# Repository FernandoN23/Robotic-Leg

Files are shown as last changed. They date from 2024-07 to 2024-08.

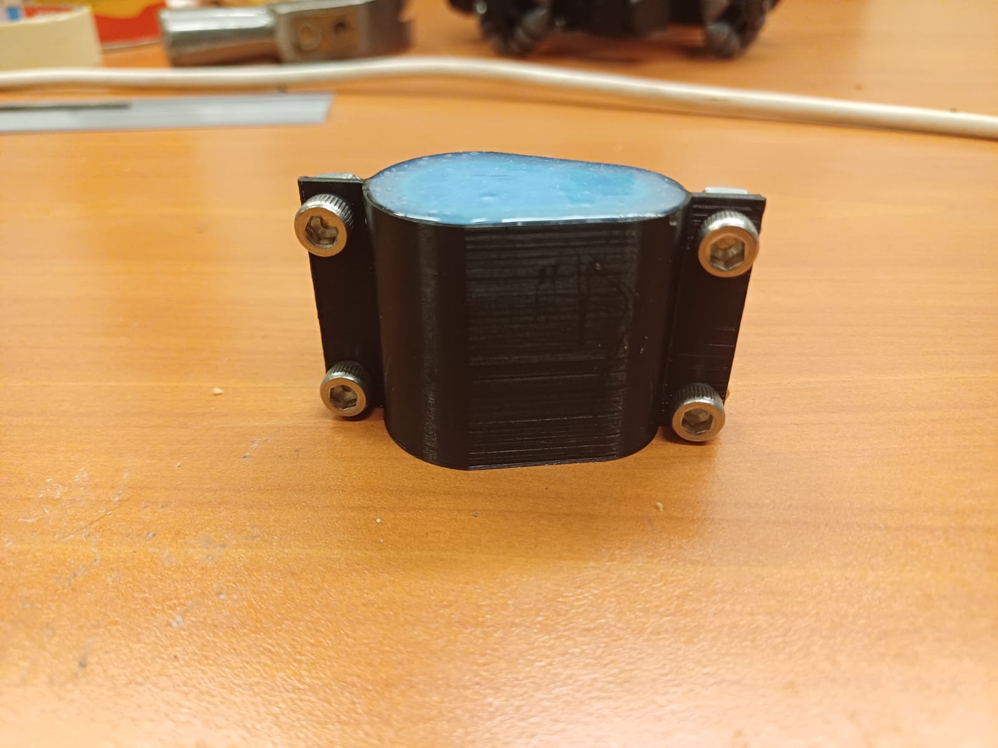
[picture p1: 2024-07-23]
Soft Robotic/Registro fotográfico/Pie mojado/Pie mojado en molde (foto 3).jpeg

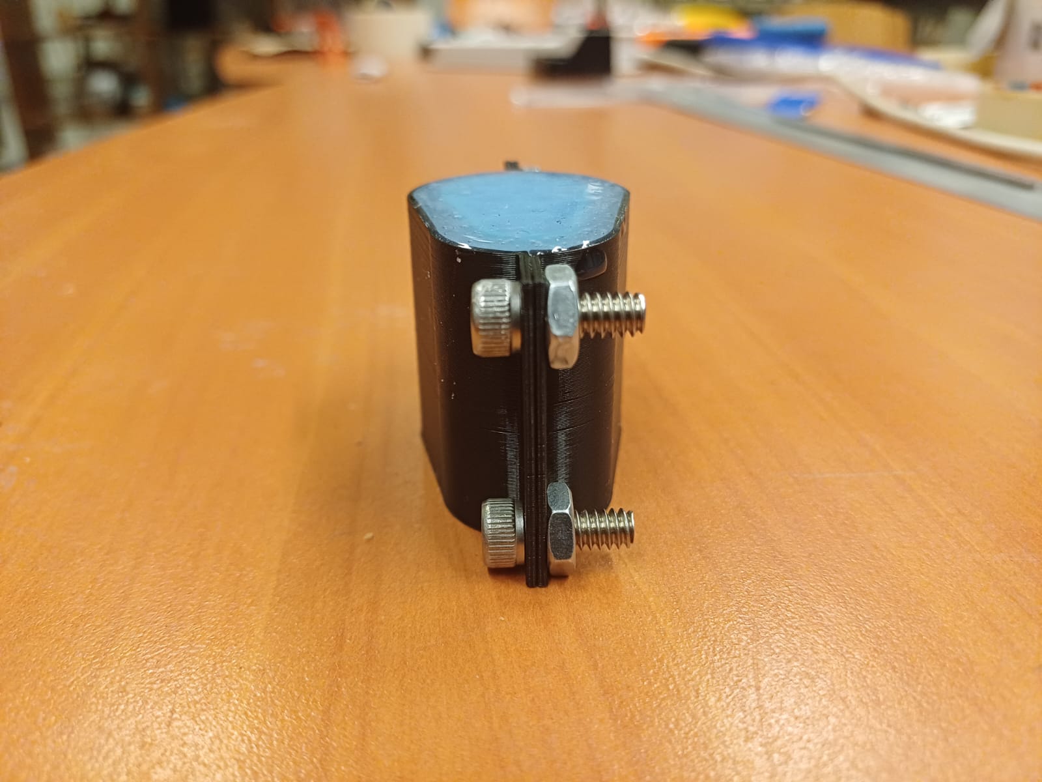
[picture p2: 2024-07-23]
Soft Robotic/Registro fotográfico/Pie mojado/Pie mojado en molde (foto 1).jpeg

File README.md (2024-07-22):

# Robotic-Leg
Proyecto de Trabajo Dirigido Avanzado ME5102 el cual consiste en la elaboración de una pata robótica utilizando robótica rígida y blanda. Elaborado en la Facultad de Ciencias Físicas y Matemáticas de la Universidad de Chile.

Objetivo general: Diseñar y manufacturar una pata robótica. 

Objetivos específicos:
- La pata robótica será un diseño híbrido, creada a partir de robótica rígida y blanda.
- La pata robótica será funcional y tendrá un enfoque educativo y didáctico.
- La pata robótica será de fácil ensamblaje para futuros proyectos y/o modificaciones.
- Esta pata será el elemento principal para un robot bípedo o cuadrúpedo.

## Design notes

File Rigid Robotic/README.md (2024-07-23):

# Robótica Rígida

En esta carpeta se encuentran todos los archivos CAD, scripts y diseños relacionados a la robótica rígida de la pata robótica.

El diseño de la pata robótica considera 4 eslabones, donde dos de ellos (pata superior e inferior) corresponden a las piezas principales y las otras se tratan de piezas que permiten la transmisión del movimiento en todo el sub-sistema dando lugar a su locomoción a través de pisadas.

Para la estructura del sub-sistema también se utilizaron los siguientes componentes comerciales:
- Rodamientos:
  - 6804 (20x32x7 mm)
  - 685 (5x11x5 mm)
- Tornillos sinfín:
  - Tornillo de largo 6,5 cm
  - Tornillo de largo 20 cm
 
Luego, para la implementación del movimiento se utilizaron los componentes comerciales electrónicos de a continuación:
- Motor Stepper NEMA 17

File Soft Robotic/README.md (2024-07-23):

# Soft Robotic

En esta carpeta se encuentran todos los archivos CADs y diseños relacionados a la robótica blanda de la pata robótica.

Se aplicaron bases de robótica blanda para diseñar el "pie" de la pata robótica. Una de las consideraciones principales de diseño para el pie de la pata fue otorgarle una característica de tipo modular, que permita no sólo cambiarlo en términos de diseño, sino que agregarle un valor agregado al desarrollo de este trabajo, puesto que esta particularidad también ofrece la oportunidad de experimentar con diferentes piezas, materialidades y geometrías.

Se llevaron a cabo dos tipos de "pie" a partir de robótica blanda: "Pie mojado" y "Pie runner".

Para el pie mojado se realizó una simulación estática. Se consideró una fuerza vertical de 700 N, donde se obtuvo un esfuerzo máximo de Von Mises de 13,825 MPa y un factor de seguridad de 3,139, considerando como material: PLA. Se tiene en cuenta un factor de seguridad mínimo aceptable de 3,0 debido a que dicho material es de tipo anisotrópico en impresión 3D.

Para la realización de las piezas se precisaron principalmente siliconas Dragon Skin™ (10 Medium), las cuales corresponden compuestos de silicona líquida curados con platino de alto rendimiento.

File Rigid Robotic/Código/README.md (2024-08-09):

Aquí se presenta el código de prueba para este sistema mecánico.

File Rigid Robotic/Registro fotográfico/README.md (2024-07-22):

# Registro fotográfico

En esta sección se almacenará todo el registro fotográfico generado a lo largo de ejecución del trabajo realizado.

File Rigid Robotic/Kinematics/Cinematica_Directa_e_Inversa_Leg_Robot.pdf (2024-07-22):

Universidad de Chile
Facultad de Ciencias Físicas y Matemáticas Departamento de Ingeniería Mecánica ME5102-2 – Trabajo dirigido avanzado

# Proyecto Pata robótica

Trabajo Dirigido Avanzado

Profesores: Rubén Fernández, Carolina Silva Estudiantes: Juan Manuel Astudillo, Francisco Cáceres, Lucas Garrido, Fernando Navarrete, Nicole Ortiz, Randy Bartolo,

## 1. Cinemática Directa

La geometría del problema a resolver se muestra a continuación en la Figura 1. Las variables articuladas son rotacionales y corresponden a q1, q2. Las constantes del problema corresponden a los largos l1, l2, l3 y α = 134.6

o − 180o = −45.4

o

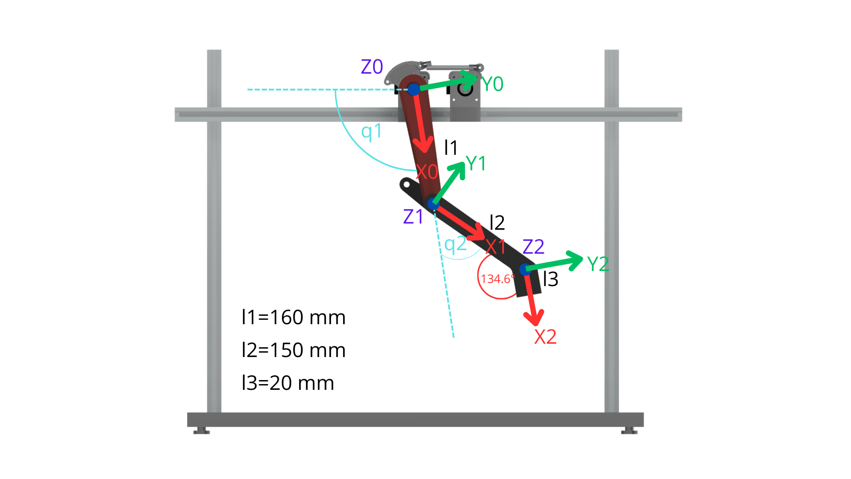
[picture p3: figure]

Figura 1: Esquema del problema a resolver.

La matriz de parámetros de Denavit-Hartenberg del problema, de acuerdo a la metodología defi-nida en la Figura 1, se muestra en la Tabla 1. Por convención se le resta al primer ángulo q1 −90o para visualizar la curva cinemática en el eje X.

Proyecto Pata robótica | 1

Tabla 1: Tabla de parámetros de Denavit-Hartenberg para el problema 1.

Articulación | Z | X
θi | di | ai | αi
1 | q1 − 90 | 0 | l1 | 0 o
2 | q2 | 0 | l2 | o 0
3 | α | 0 | l3 | o 0

Observación: θi
, di son las rotaciones y traslaciones con respecto al eje Zi y ai

, αi son las traslaciones y rotaciones con respecto al eje Xi. respectivamente
La matriz homogénea de acuerdo al Algoritmo de Denavit-Hartenberg es:

A

i
i−1 = Rotz(θi) · T(0, 0, di) · T(ai
, 0, 0) · Rotx(αi) | (1)

A

i
i−1 =

Cθi | −CαiSθi | SαiSθi | aiCθi
Sθi | CαiCθi | −SαiCθi | aiSθi
0 | Sαi | Cαi | di
0 | 0 | 0 | 1

(2)

Donde Cθi = cos(θi) y Sθi = sen(θi). Lo mismo para el ángulo αi . Las matrices homogéneas D-H de acuerdo a la Tabla 1 son:

A

1
0 =

sen(q1) | cos(q1) 0 | l1sen(q1)
−cos(q1) sen(q1) 0 −l1cos(q1)
0 | 0 | 1 | 0
0 | 0 | 0 | 1

(3)

A

2
1 =

cos(q2) −sen(q2) 0 l2cos(q2)
sen(q2) | cos(q2) | 0 l2sen(q2)
0 | 0 | 1 | 0
0 | 0 | 0 | 1

(4)

A

3
2 =

cos(α) −sen(α) 0 l3cos(α)
sen(α) | cos(α) | 0 l3sen(α)
0 | 0 | 1 | 0
0 | 0 | 0 | 1

(5)

Para este problema, la matriz de transformación homogénea aplicado al caso de cinemática directa, resulta en la ponderación de las matrices Ai
i−1 desde 0 hasta el último eslabón n = 3. Es decir:

T

3
0 = A

1/0· A

2/1· A

3
2

(6)

T

3
0 =

sen(q1 + q2 + α) cos(q1 + q2 + α) sen(q1 + q2 + α) cos(q1 + q2 + α)
0 | 0
0 | 0

0 l1 · sen(q1) + l2 · sen(q1 + q2) + l3 · sen(q1 + q2 + α) 0 −l1 · cos(q1) − l2 · cos(q1 + q2) − l3 · cos(q1 + q2 + α)
1 | 0
0 | 1

De esta forma, las posiciones son:

Px = l1 · sen(q1) + l2 · sen(q1 + q2) + l3 · sen(q1 + q2 + α) | (7)
Py = −l1 · cos(q1) − l2 · cos(q1 + q2) − l3 · cos(q1 + q2 + α) | (8)
γ = q1 + q2 + α | (9)

A continuación se muestra el resultado de implementarlo en Python:

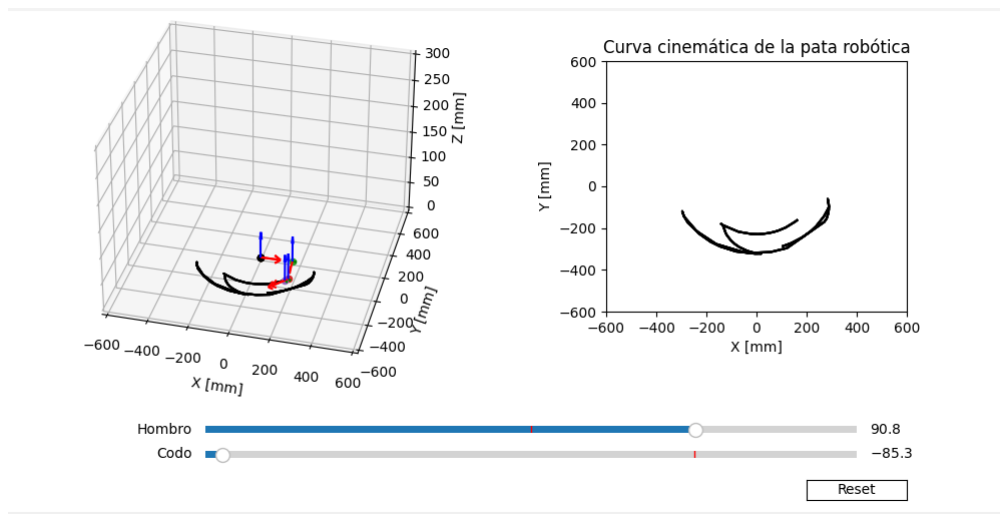
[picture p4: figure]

Figura 2: Resultado de implementación de la cinemática directa del robot. Es posible visualizar los ejes de las variables articuladas y la curva cinemática que describe el efector o pata del robot.

## 2. Cinemática inversa

Se utilizará el método geométrico para determinar la cinemática inversa a partir de las funciones de cinemática directa obtenidas anteriormente. Se utilizará de referencia el artículo de Juecoree [? ]. Recordemos que las posiciones de la pata son descritas mediante las siguientes ecuaciones:

Px = l1 · sen(q1) + l2 · sen(q1 + q2) + l3 · sen(q1 + q2 + α) | (10)
Py = −l1 · cos(q1) − l2 · cos(q1 + q2) − l3 · cos(q1 + q2 + α) | (11)
γ = q1 + q2 + α | (12)

Vamos a considerar de momento que las posiciones son consideradas sin la rotación de −90o y luego aplicarla al final de los ángulos obtenidos de la cinemática inversa. De esta forma, la posición existente antes del tobillo puede reescribirse como:

Px,0−2 = Px − l3cos(γ) | (13)
Py,0−2 = Py − l3cos(γ) | (14)

Los ángulos internos formados por los links de la pata robótica se calculan como:

δ = cos⁻¹
(

P

2
x,0−2 + P

2
y,0−2 − l

2
1 − l

2
2
2 · l1l2
) | (15)

β = sen⁻¹
(

l2sen(δ)
q
P

2
x,0−2 + P

2
y,0−2
) | (16)

Las posibles configuraciones de la posición inversa se muestran en la Figura 3.

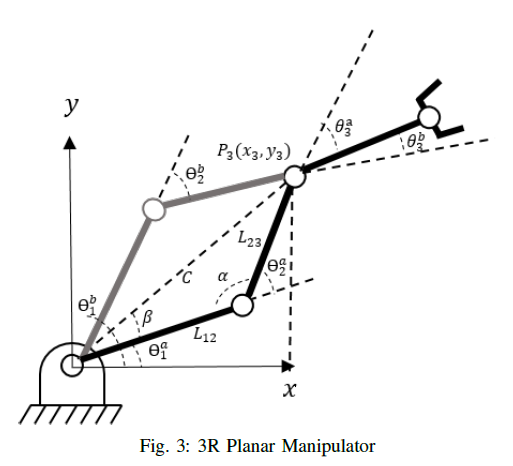
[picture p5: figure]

Figura 3: Configuraciones cinemática inversa planar de 3 links

De esta forma, se definen los ángulos posibles de cada articulación para los casos a) y b):

θ

a
1 =

tan⁻¹ Py,0−2

Px,0−2

− β

!
θ

b
1 = θ

a
1 =

tan⁻¹ Py,0−2

Px,0−2

+ β

!
(17)

θ

a
2 = (180 − α)θ

b
2 = −(180 − α) | (18)

Por último, se tiene que los ángulos asociados al tercer link son:

θ

a
3 = γ − θ

a
1 − θ

a
2

(19)

θ

b
3 = γ − θ

b
1 − θ

b
2

(20)

Con esto es posible obtener la cinemática inversa del robot considerando una solución única de θ3.

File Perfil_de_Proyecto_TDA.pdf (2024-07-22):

Facultad de Ciencias Físicas y Matemáticas

# Perfil del proyecto

Walking Robot

Profesores: Rubén Fernández, Carolina Silva Integrantes: Fernando Navarrete, Francisco Cáceres, Juan Astudillo, Lucas Garrido, Nicole Ortiz, Randy Bartolo

## 1. Objetivos generales y específicos

### 1.1. Objetivo general

El objetivo general del trabajo dirigido avanzado es diseñar y manufacturar una pata robótica.

### 1.2. Objetivos específicos

A su vez, se dará cumplimiento de los siguientes objetivos específicos.

1. La pata robótica será creada de robótica híbrida (robótica rígida y blanda).
2. La pata robótica será funcional.
3. Tendrá un enfoque educativo y didáctico.
4. La pata robótica será de fácil ensamblaje para futuros proyectos y/o modificaciones.
5. Esta pata será el elemento principal para un robot bípedo o cuadrúpedo.

## 2. Fases y plan de trabajo

### 2.1. Fases

Las fases específicas que se llevarán a cabo durante el trabajo dirigido avanzado se enumeran a continuación con sus respectivas fechas tentativas.

1. (Semana 5) Elaborar mesa de pruebas para probar la pata robótica. La altura será ajustable de acuerdo a los requerimientos dimensionales de la pata robótica.
2. (Semana 6) Elegir proporción de robótica rígida y blanda para el pie del robot.
3. (Semana 6-8) Realizar prototipos
4. (Semana 8-9) Elaborar hombro preliminar, lo cual considera la implementación de un motor, caja reductora, rodamientos y carcasa.
5. (Semana 8-9) Elaborar cuerpo preliminar de la pata robótica a partir de algún proceso de manufactura: impresión 3D, sistemas modulares, cartón, etc.
Perfil del proyecto | 1

6. (Semana 10) Ensamblar y prototipar con Arduino y electrónica básica.
7. (Semana 11-12) Validar numéricamente los protipos.
8. (Semana 13-14) Ensamblar y prototipar con Arduino y electrónica básica.
9. (Semana 15) Una vez se comprueba la funcionalidad del prototipo, mejorar el diseño utilizando materiales definitivos y mas robustos.

### 2.2. Plan de trabajo

Como plan de trabajo se tienen contemplados distintos horarios a la semana, los días lunes a las 20:00 hrs se realizaran reuniones virtuales para evaluar los avances y objetivos a cumplir, mientras que los días miércoles desde las 12:00 hrs serán destinados a trabajo presencial. Los integrantes del equipo están dispuestos a cumplir con estos horarios además de ofrecer algunas horas fuera de estos horarios dedicadas al proyecto. Las distintas tareas del proyecto se irán dividiendo entre los integrantes del equipo, con tal de realizar trabajos de forma paralela.

También se contemplan reuniones con la profesora Carolina Silva cada dos semanas para mostrar los avances y recibir retroalimentación.

## 3. Bosquejos iniciales y referencias

### 3.1. Idea cuerpo robot

El cuerpo robótico (ver figura 1) contará con cuatro patas, y además subsistemas que tengan que ver con la estructura interna, externa y los pies, en los cuales se espera poder implementar robótica blanda, con el fin de construir un robot híbrido. Por otra lado, en la parte inferior de la figura, se muestran ejemplos posibles de pies a utilizar, uno de tipo helicoidal y otro de tipo de pie donde se utiliza control de presión.

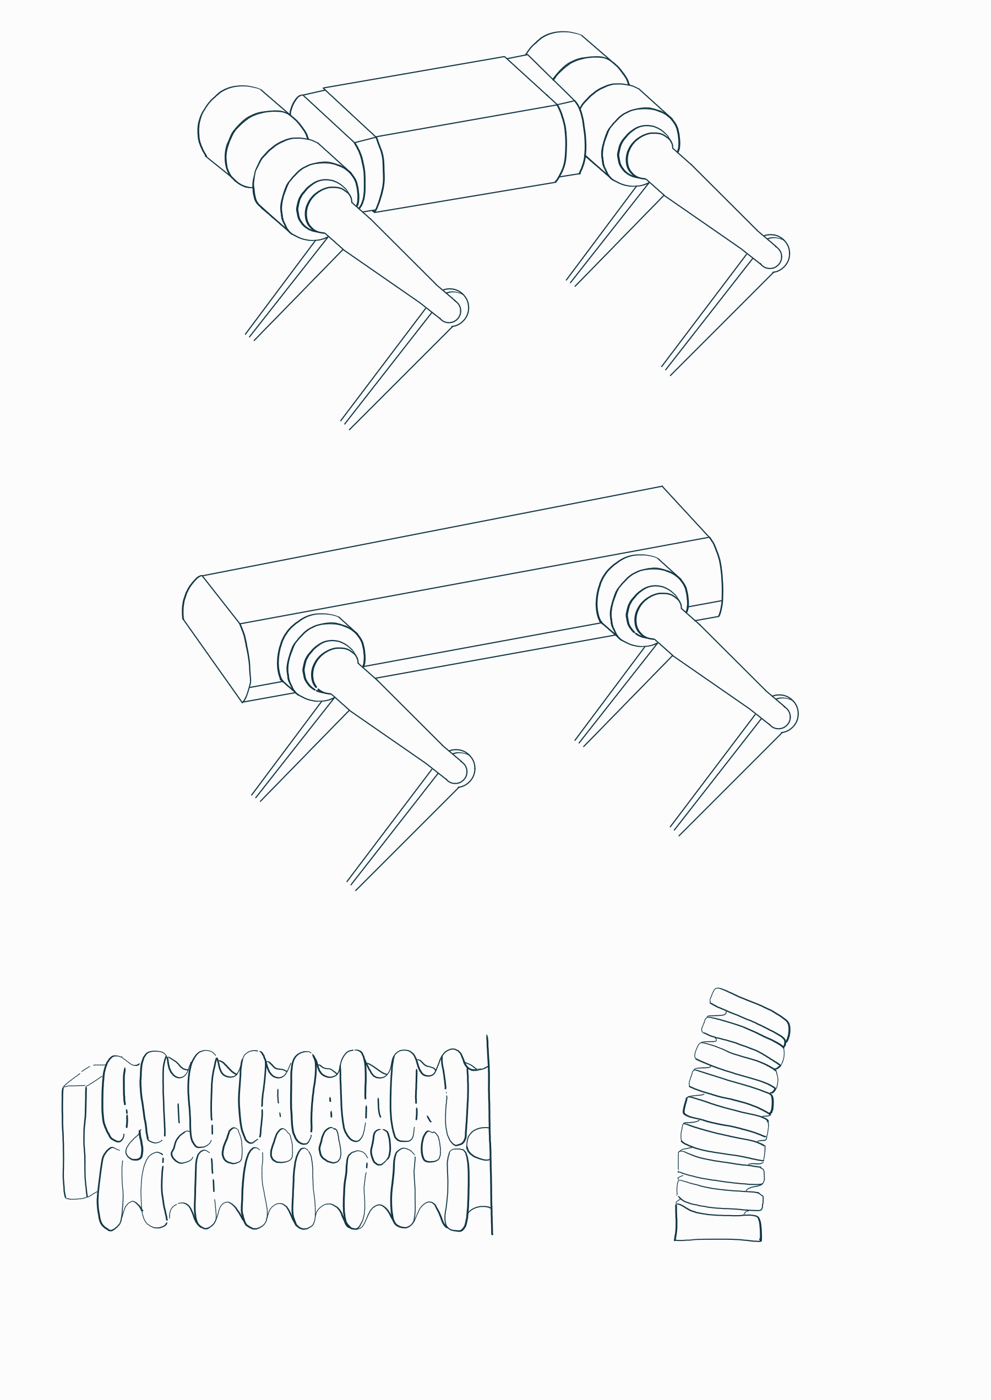
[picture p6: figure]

Figura 1: Bosquejo cuerpo de robot

### 3.2. Idea pie tipo garra

Con el fin de innovar el diseño en relación a varios papers investigados, se pretende utilizar una garra en el pie de la pata robótica, tal como se muestra en la Figura 2.

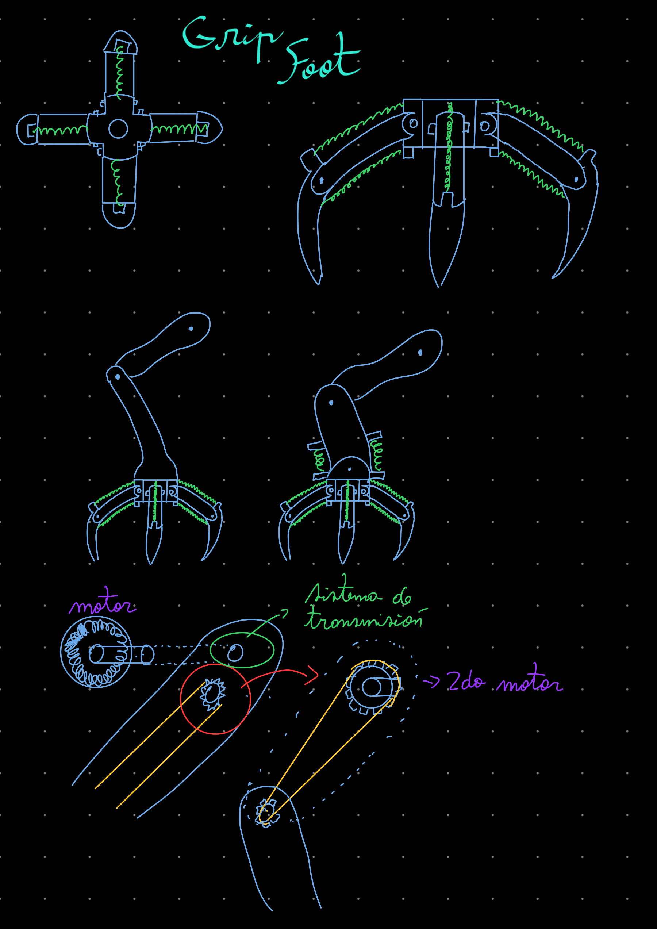
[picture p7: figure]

Figura 2: Bosquejo idea tipo garra del pie robótico mas posibles uniones al resto de la pata robótica y transmisión del movimiento.

### 3.3. Idea mesa de pruebas

Para realizar las pruebas de la pata robótica a elaborar, se requiere una mesa de pruebas para poder facilitar el movimiento de la pata robótica sin la necesidad de un cuerpo. Para esto, se elaboró un bosquejo de la posible mesa de pruebas a utilizar, la cual se muestra en la Figura 3.

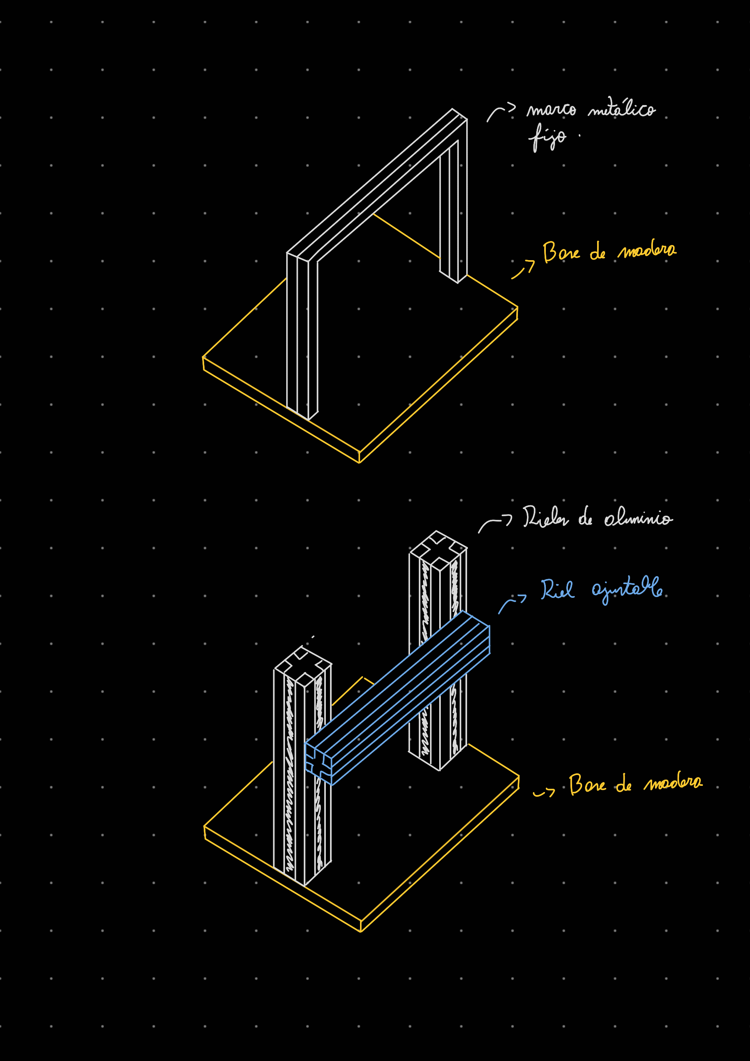
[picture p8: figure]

Figura 3: Bosquejo mesa de pruebas con base de madera y perfiles de rieles de aluminio que sostendrán la pata robótica.

## Referencias

[1] Kyunam Kim1†, Patrick Spieler1†, Elena-Sorina Lupu1, Alireza Ramezani1,2, Soon-Jo Chung1,3. (2021). A bipedal walking robot that can fly, slackline, and skateboard. Science Robotics.
[2] Alexander Badri-Spröwitz1*†, Alborz Aghamaleki Sarvestani1†, Metin Sitti2,3,4, Monica A. Daley5,6. (2022). BirdBot achieves energy-efficient gait with minimal control using avian-inspired leg clutching. Science Robotics.
[3] Stefano Rodinò, Elio Matteo Curcio , Antonio di Bella, Mattia Persampieri, Michele Funaro and Giuseppe Carbone *. (2020). Design, Simulation, and Preliminary Validation of a Four-Legged Robot. Machines.
[4] Pandu Ranga Vundavilli⋆, Sambit Kumar Sahu†, and Dilip Kumar Pratihar‡. (2006). Dynamically balanced ascending and descending gaits of a two-legged robot. International Journal of Humanoid Robotics Vol. 4, No. 4 (2007).
[5] Takuma Nemoto, 1 Rajesh Elara Mohan,2 and Masami Iwase. (2015). Rolling Locomotion Control of a Biologically Inspired Quadruped Robot Based on Energy Compensation. Journal of Robotics.

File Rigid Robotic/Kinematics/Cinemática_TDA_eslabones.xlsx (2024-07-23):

 | Datos
 | L1 | 0.0306 | m
 | L2 | 0.065 | m
 | H | 0.045 | m
 | m1 | 0.5 | kg
 | m2 | 1.2 | kg
 | I1 | -0.0001276 | kg m2
 | I2
 | dg1 | 0.0153 | m
 | dg2 | 0.0325 | m
 | g | 9.82 | m/s2
 | D | 0.65 | m
 | Dg | 0.325 | m
 | M | 20 | kg
 | d | 0.2153659496 | m
 | v | 1 | m/s
 | h | 0.1 | m
 | f | 2.32162977 | pisadas/s |  |  |  |  | 70
 | T | 0.4307318992 | s |  |  |  |  | 70
 | T/2 | 0.2153659496 | s |  |  |  |  | 70
 | Ty | 0.1076829748 | s |  |  |  |  | 70
 | w | 14.58723006 | rad/s |  |  |  |  | 70
 | w1 | 29.17446012 | rad/s | -147.1376632 | -128.6141463 |  |  | 40
 | w2 | 58.34892023 | rad/s | 429.5098763 | 248.9471393 |  |  | 65 |  |  | velocidad maxima correa | 0.2177038391 | m/s |  |  |  |  |  |  |  |  |  |  |  |  |  |  |  |  |  |  |  |  |  |  |  |  |  |  | -42.99236353 | -4.720033804 | -16.22570465 |  |  |  | -43.08969655 | 2.371757857 | -17.12994264 |  |  |  | -6.689331031 |  |  | -6.468822452 | -130.6135114
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

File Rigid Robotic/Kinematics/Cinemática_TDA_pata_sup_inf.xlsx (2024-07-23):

 | Datos
 | L1 | 0.16 | m
 | L2 | 0.15 | m
 | H | 0.25 | m
 | m1 | 0.5 | kg
 | m2 | 1.2 | kg
 | I1 | -0.0001276 | kg m2
 | I2
 | dg1 | 0.08 | m
 | dg2 | 0.075 | m
 | g | 9.82 | m/s2
 | D | 0.65 | m
 | Dg | 0.325 | m
 | M | 20 | kg
 | d | 0.2153659496 | m
 | v | 1 | m/s
 | h | 0.1 | m
 | f | 2.32162977 | pisadas/s |  |  |  |  | 70
 | T | 0.4307318992 | s |  |  |  |  | 70
 | T/2 | 0.2153659496 | s |  |  |  |  | 70
 | Ty | 0.1076829748 | s |  |  |  |  | 70
 | w | 14.58723006 | rad/s |  |  |  |  | 70
 | w1 | 29.17446012 | rad/s | 0.8022629637 | 2.81755733 |  |  | 40
 | w2 | 58.34892023 | rad/s | 74.46495574 | 79.52985302 |  |  | 65 |  |  | velocidad maxima correa | 0.2177038391 | m/s |  |  |  |  |  |  |  |  |  |  |  |  |  |  |  |  |  |  |  |  |  |  |  |  |  |  | -41.96994413 | -13.2719522 | -1.994086328 |  |  |  | -43.08969655 | -17.43103536 | -17.12994264 |  |  |  | -12.60133404 |  |  | -5.605035465 | -130.6135114
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

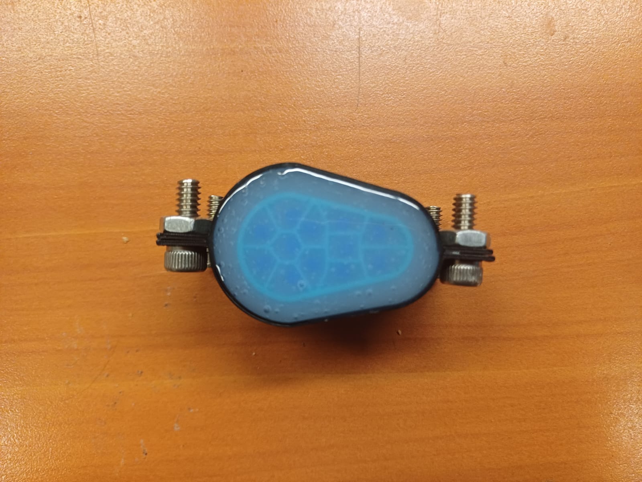
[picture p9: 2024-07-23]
Soft Robotic/Registro fotográfico/Pie mojado/Pie mojado en molde (foto 2).jpeg

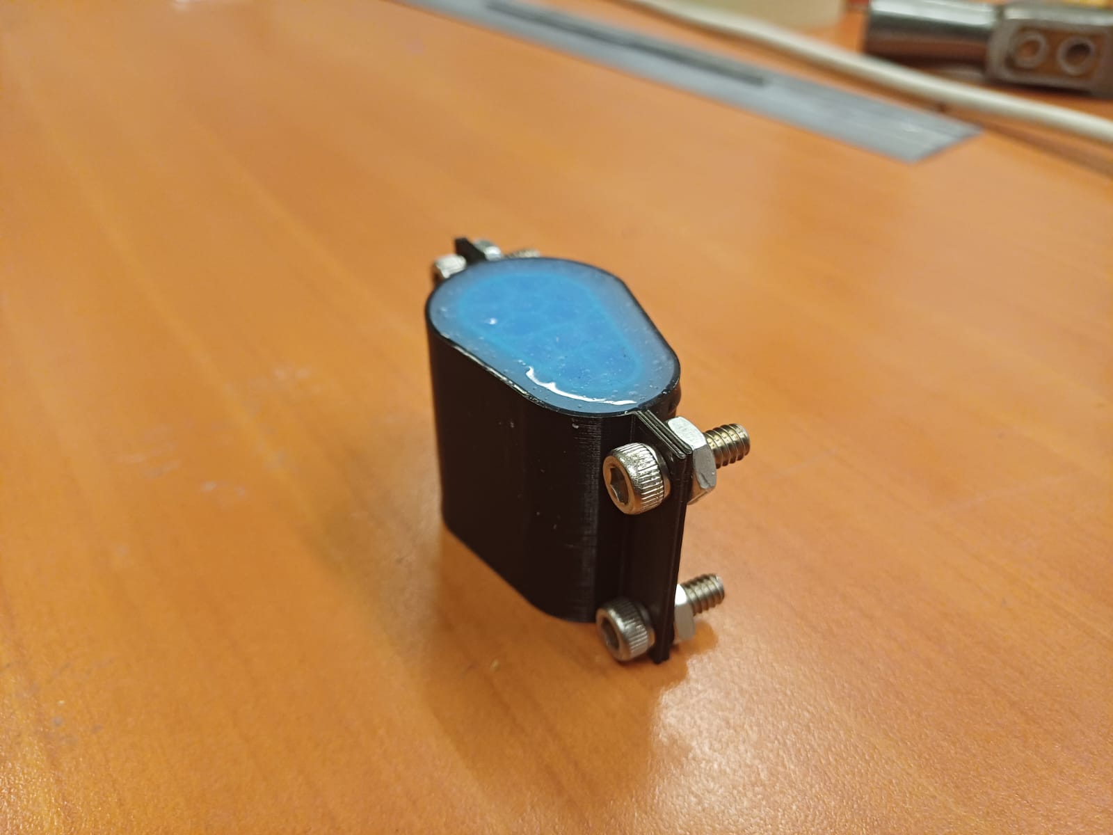
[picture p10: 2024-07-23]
Soft Robotic/Registro fotográfico/Pie mojado/Pie mojado en molde (foto 4).jpeg

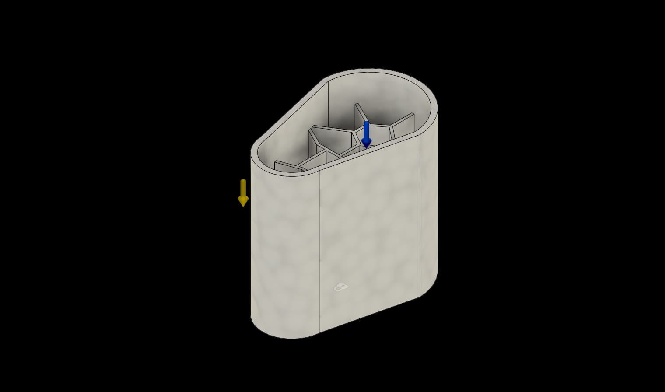
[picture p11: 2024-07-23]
Soft Robotic/Registro fotográfico/Pie mojado/Condiciones de borde pie mojado.jpeg

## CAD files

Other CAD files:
Rigid Robotic/CAD/Mini eslabón.f3d
Rigid Robotic/CAD/Mini soporte.f3d
Rigid Robotic/CAD/Pata inferior.f3z
Rigid Robotic/CAD/Soporte.f3d
Rigid Robotic/CAD/Tapa de rodamiento pata superior.f3d
Rigid Robotic/CAD/Tapa rodamiento (90°).f3d
Soft Robotic/CAD/Pie mojado/Ensamble Pie mojado.f3z
Soft Robotic/CAD/Pie mojado/Molde Exterior.f3d
Soft Robotic/CAD/Pie mojado/Molde Interior.f3d
Soft Robotic/CAD/Pie mojado/Molde fijo.f3d
Soft Robotic/CAD/Pie mojado/Tapa.f3d

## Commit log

2024-07-22 Create CAD
2024-07-22 Update and rename Leg_robot.py to Kinematics_Leg_robot.py
